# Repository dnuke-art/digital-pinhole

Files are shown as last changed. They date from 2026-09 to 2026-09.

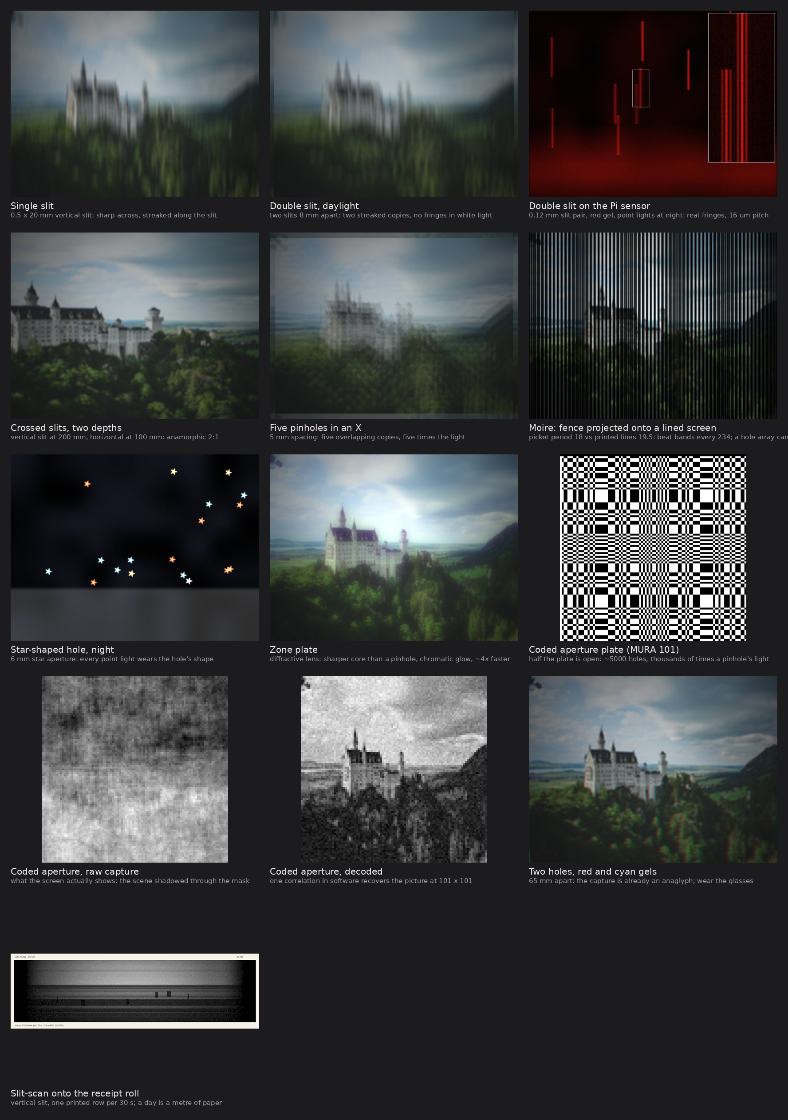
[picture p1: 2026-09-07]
mockups/out/experiments_sheet.png

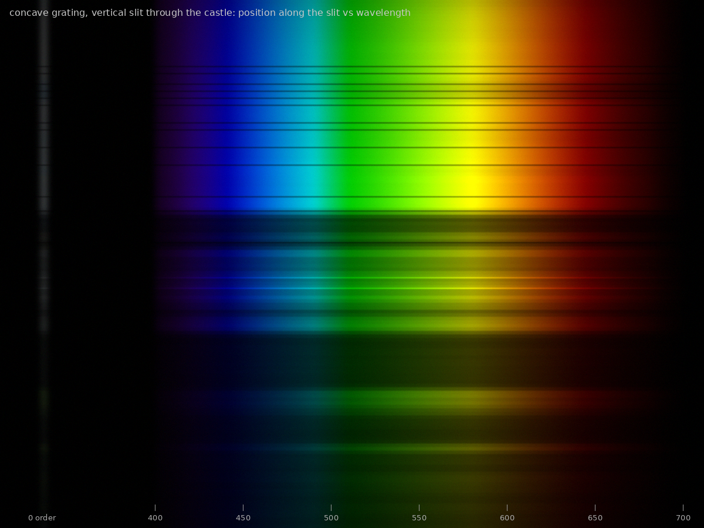
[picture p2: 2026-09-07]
mockups/out/look4_01_spectrograph_day.png

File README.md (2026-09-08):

# Digital Pinhole

Notes toward a digital pinhole camera, started while showing analog pinhole
work at an art show (September 2026). The question was simple: can a pinhole
camera be built with a digital sensing element, and what does it look like?

Short answer: yes, three ways, and the interesting one is a camera obscura
with a small camera inside looking back at the projection.

Loose ideas go in [IDEAS.md](IDEAS.md); the ones that grow get a numbered note below.
Pictures of all of it are in [mockups/](mockups/README.md): simulated output looks, cross-section diagrams, a 3D cutaway. `make` regenerates them.

## Documents

| File | What it covers |
|---|---|
| [docs/01-approaches.md](docs/01-approaches.md) | The three viable designs and how they compare |
| [docs/02-pinhole-physics.md](docs/02-pinhole-physics.md) | Hole sizing, diffraction, resolution vs format, exposure |
| [docs/03-scanner-camera.md](docs/03-scanner-camera.md) | Flatbed scanner as sensor: why it works with a lens and not a pinhole |
| [docs/04-relay-camera-obscura.md](docs/04-relay-camera-obscura.md) | The chosen direction: pinhole box with a relay camera inside |
| [docs/05-thermal-paper.md](docs/05-thermal-paper.md) | Thermal paper: why it cannot be film, sun-trace recorder, receipt printer as output |
| [docs/06-diy-chemistry.md](docs/06-diy-chemistry.md) | DIY chemistry: cyanotype as print side, caffenol, hand-coated emulsion, solargraphy, no-fixer processes |
| [docs/07-wet-plate-pinhole.md](docs/07-wet-plate-pinhole.md) | Wet plate collodion through a pinhole: the wet-window clock, exposure, plate back, chemistry, day-one plan |
| [docs/08-apertures-and-dither.md](docs/08-apertures-and-dither.md) | Slits, shaped holes, zone plate, coded aperture, anaglyph holes, slit-scan, where moire really comes from, dither catalogue |
| [docs/09-diffraction-grating.md](docs/09-diffraction-grating.md) | Grating as lens: linear grating disperses (night spectra), zone plate focuses; numbers, chromatic behaviour, digital deconvolution, how to make one |
| [docs/10-curved-grating.md](docs/10-curved-grating.md) | Curved grating: the Rowland concave-grating spectrograph box, rainbow-ring aperture, FreeCAD Optics Workbench ray traces and what they can and cannot simulate |
| [docs/11-printed-lenses-110-and-instant.md](docs/11-printed-lenses-110-and-instant.md) | The SLO and printed lenses (dip, spin-cure, droplet lens, the relay box as test rig), the 110 cartridge camera, peel-apart and Instax, home-made diffusion transfer, Instax Link as digital output |

## Where this is headed

A wooden or printed box, a pinhole plate on the front, a matte white screen on
the back wall, and a Raspberry Pi camera mounted beside the hole photographing
the screen with multi-minute exposures. It is a slow camera on purpose. The
box is the sculpture and the screen beside it shows what the box has seen.

Next steps once a box size is chosen:

- [x] Mockups: simulated looks, cross-section diagrams, 3D cutaway (mockups/)
- [x] FreeCAD Optics Workbench ray traces of the grating ideas (make optics)
- [ ] Pick box depth and screen size (sets hole diameter and field of view)
- [ ] Decide on a swappable back: screen + camera vs plate holder
- [ ] build123d model of the box, pinhole plate, and camera mount
- [ ] Capture script: long exposure on button press, optional frame stacking
- [ ] Display: e-ink or small monitor next to the prints
- [ ] Receipt printer output: ESC/POS over USB, dither pipeline, auto-cutter
- [ ] Digital negative pipeline: invert, curve, print transparency, cyanotype contact print
- [ ] Wet plate: kit, six 4x5 plates, silver-proof holder, one sunny afternoon
- [ ] Lens plate for the relay box (live mode) and Instax Link output
- [ ] 110 pinhole box and a printed Pa-110 developing reel

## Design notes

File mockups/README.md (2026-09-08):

# Mockups

Plain Python generators (numpy, Pillow, matplotlib, scipy) plus a 3D
section of the relay box (build123d + OpenSCAD). From the repo root:

    make            # everything, about half a minute
    make deps       # check what is installed
    make looks | diagrams | experiments | gratings | render
    make photos     # fetch the sample photos (done automatically when needed)
    make clean      # remove generated images

Or run a generator directly:

    python3 mockups/looks.py       # simulated output images -> out/look_*.png, looks_sheet.png
    python3 mockups/diagrams.py    # cross-section diagrams  -> out/diag_*.png, diagrams_sheet.png
    python3 mockups/render3d.py    # 3D cutaway render        -> out/render_relay_cutaway.png
    python3 mockups/looks2.py      # aperture experiments + dither styles -> out/look2_*.png, dither_*.png, experiments_sheet.png, dither_sheet.png
    python3 mockups/looks3.py      # gratings and zone plate -> out/look3_*.png, grating_sheet.png
    python3 mockups/looks4.py      # curved gratings -> out/look4_*.png, curved_grating_sheet.png
    make optics                    # FreeCAD Optics Workbench ray traces -> out/optics_*.png (needs freecadcmd + addon)

Sample photos in `src/` are from picsum.photos (Unsplash) and are only here
as stand-ins for the simulations.

## Output looks (`out/look_*.png`)

Simulations of what each approach's picture looks like, all from the same
source photo so they compare directly. Sheet: `out/looks_sheet.png`.

| File | Approach | What is simulated |
|---|---|---|
| look_01_relay_digital | relay camera obscura | ~200 points across, cos^4 falloff over a 65° field, flare, long-exposure noise |
| look_02_fullframe_bodycap | full-frame body cap | ~180 points, 90° field falloff |
| look_03_pi_hq_direct | Pi HQ, lens off | ~45 points, steep-ray vignetting and magenta corner shift |
| look_04_receipt | receipt printer | relay frame at 384 dots, Floyd-Steinberg, 58 mm paper with caption |
| look_05_cyanotype | cyanotype from digital negative | Prussian blue on cream paper, brushed coating edge, uneven coat |
| look_06_collodion_landscape | wet plate pinhole, ambrotype | blue/UV-only response (white sky, dark foliage), ~110 points, pour marks, black backing |
| look_07_collodion_portrait | wet plate pinhole, portrait | red lips go black, skin goes luminous |
| look_08_solargraph | solargraphy | months of nested sun arcs, inverted paper-negative tones |
| look_09_sun_trace | sun-trace recorder | thermal strip with a burnt daily arc broken by clouds |
| look_10_heliograph | bitumen heliograph | pewter plate, only highlights harden, very low contrast |

The simulations are optics-first (resolution, falloff, spectral response)
with the surface character (pour marks, paper grain, dither) added on top.
They are for judging the look, not for exposure planning.

## Aperture experiments (`out/look2_*.png`, sheet `experiments_sheet.png`)

Single slit, double slit in daylight, double slit with real fringes on the
Pi sensor, crossed slits (anamorphic), five-hole X, moire from a lined
screen, star-shaped hole at night, zone plate, MURA coded aperture (mask,
raw, decoded), red/cyan two-hole anaglyph, slit-scan receipt strip.
Physics in [docs/08](../docs/08-apertures-and-dither.md).

## Gratings (`out/look3_*.png`, sheet `grating_sheet.png`)

Linear grating over the pinhole at night and in daylight, the zone plate
pattern, the zone plate as captured in white light, and the digital fix
(halo subtraction, luminance from green). Physics in [docs/09](../docs/09-diffraction-grating.md).

## Curved gratings (`out/look4_*.png`, sheet `curved_grating_sheet.png`)

Concave grating spectrograph in daylight (slit through the castle) and at
night (lamp fingerprints), and the circular constant-pitch aperture with
rainbow rings. Physics in [docs/10](../docs/10-curved-grating.md).

## FreeCAD ray traces (`out/optics_*.png`)

`fc_optics.py` runs under FreeCAD's own python (the AppImage in `/opt`,
`freecadcmd` entry point, offscreen Qt) with the OpticsWorkbench addon and writes hit
coordinates to JSON and saves the FreeCAD document (`optics_*.FCStd`, open
it in FreeCAD with the addon installed to see the rays); `optics_plot.py` plots the hits. Two scenes: a 500 l/mm
film behind the pinhole, and the Rowland concave-grating spectrograph.
`make optics` builds both. Not in `make all` because it needs FreeCAD;
`make deps` reports whether the AppImage and the addon are available.
Override with `make optics FREECADCMD="path/to/freecadcmd"`.

## Dither styles (`out/dither_*.png`, sheet `dither_sheet.png`)

The relay frame rendered as Floyd-Steinberg, Atkinson, Bayer 4x4 and 8x8,
45-degree halftone, line screen, Game Boy Camera (128x112, four greens),
CGA palette 1, and 1-bit at 96 px.

## Diagrams (`out/diag_*.png`)

Cross sections in millimetres. Sheet: `out/diagrams_sheet.png`.

1. Relay camera obscura, side section
2. Wet plate pinhole, shallow box with plate holder
3. One body, two backs, exploded
4. Pi HQ camera with the sensor directly behind the hole, 6x scale
5. Full-frame body cap
6. Sun-trace recorder on thermal paper
7. Dubroni-style in-camera wet plate processing
8. Show layout, elevation

## 3D (`out/render_relay_cutaway.png`)

The relay box with the near side wall removed: pinhole plate, camera beside
the hole, Pi, matte screen, light cone, receipt printer on the lid. Built in
build123d so the same file can grow into the real part model.

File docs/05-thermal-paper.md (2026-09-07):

# Thermal paper as film

Asked: can thermal (receipt) paper be used as the film in a pinhole camera?

Not by direct exposure. Two things do work: burning the sun's path with a
lens, and using a thermal printer as the camera's output. The second fits
this project unusually well.

## Why direct exposure cannot work

Thermal paper is a heat medium. The leuco dye and developer in the coating
react when it passes roughly 65 to 70 degrees C (some durable grades need
90+). Light only matters insofar as it heats the sheet.

Rough budget, still air, room temperature:

| Quantity | Value |
|---|---|
| Temperature rise needed | ~45 K |
| Convective loss coefficient | ~10 W/m^2/K |
| Absorptance of white thermal paper | ~0.15 |
| Irradiance needed to hold that rise | 45 * 10 / 0.15 = ~3000 W/m^2, about 3 suns |
| Direct sunlight | ~1000 W/m^2, 1 sun |
| Sunlit scene through an f/300 pinhole | ~0.002 W/m^2 |

A pinhole cannot concentrate light. The most it can ever deliver is slightly
under one sun, and only for an image of the sun itself. A sunlit scene
through the box arrives about six orders of magnitude short. Pre-warming the
sheet toward its threshold does not help: the margin needed is smaller than
the sheet-to-sheet and spot-to-spot variation, so the whole page develops.

Thermal paper also slowly darkens under months of UV and ambient light. Not
usable through a pinhole; too weak and too uneven.

## What works: burning the sun's path

The Campbell-Stokes sunshine recorder is a glass sphere that focuses the sun
onto a card and burns a trace across the day. Concentration through a lens
at f/2 is on the order of thousands of suns, so thermal paper develops
easily and at far lower power than charring. Even a marble or a small cheap
lens will leave a track. Gaps in the trace are clouds.

This is the thermal cousin of solargraphy (months of sun tracks recorded
through a pinhole onto photo paper). It needs a lens because only a lens
concentrates; a big pinhole yields a faint blurred sun disc under one sun
and nothing happens.

As an object: a glass sphere or lens on a stand, a curved thermal paper
strip behind it, changed daily. Thermal paper as film, with the sun as the
only subject.

## The fit for this project: thermal paper as output

Put a receipt printer on the relay box. The camera exposes, prints the frame,
cuts it. Visitors take it. The print fades over the next year or two because
thermal prints do, which suits the medium.

The resolution numbers line up:

| Item | Width | Dots or points across |
|---|---|---|
| Pinhole image on a 250 mm screen | 250 mm | ~200 real points |
| 58 mm receipt printer, 203 dpi | 48 mm printable | 384 |
| 80 mm receipt printer, 203 dpi | 72 mm printable | 576 |

The pinhole image carries fewer real points than the printer has dots. The
receipt loses nothing. Tone comes from dithering (Floyd-Steinberg or ordered
for a coarser look) or from the printer's native grayscale mode where it has
one.

Practical:

- Cheap ESC/POS printers drive from a Pi over USB or serial. `python-escpos`
  handles image printing.
- Pick a printer with an auto-cutter if prints are handed out.
- Thermal paper rolls are cheap; buy phenol-free stock if people will handle
  them.
- Keep the printer out of the light path and its head warmth away from the
  camera.

## Larger thermal prints: laser scanning

For prints bigger than a receipt, scan a low-power laser diode across
fax-roll thermal paper (216 mm width, still sold). Hobby engravers at very
low power develop the coating rather than burn it. Same dither pipeline, one
extra machine. Ventilate: heated thermal coatings release bisphenol vapor.

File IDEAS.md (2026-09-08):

# Ideas

Running list. Loose thoughts land here first; the ones that grow get a
numbered note in `docs/`. Mark status inline.

## Cameras

- **Relay camera obscura** — pinhole box, matte screen, Pi camera beside the
  hole. The main build. → docs/04
- **Walk-in version** — same idea at room scale for the show. Blackout a
  room or a big crate, hole in one wall, camera on a tripod inside doing
  minute-long frames. Morell's move. Untested; needs a dark enough space.
- **Swappable back on the relay box** — screen + Pi camera in one back, a
  4x5/5x7 plate holder in another. Same box shoots digital and wet/dry plate.
- **8x10 or larger relay box** — sharper (~300+ points across) and slower.
  Only if the gallery light budget allows.
- **Full-frame body cap pinhole** — better instrument than the box, worse
  object. Keep as the fast way to make digital pinhole images. → docs/01
- **Pi HQ camera, lens off** — small, bright, soft. Live video outdoors.
  Good for a handheld or a video piece. → docs/01
- **Scanner camera with a lens** — separate project; time-smear aesthetic on
  a letter-size format. Not pinhole. → docs/03
- **Sun-trace recorder** — Campbell-Stokes on thermal paper. Glass sphere or
  lens, curved thermal strip, changed daily. Thermal paper as film for the
  one subject bright enough. → docs/05
- **Solargraphy cans** — months-long pinhole exposures on photo paper, no
  developer. Uses existing cameras. → docs/06

- **Double-slit slide in the Pi HQ cap** — fringes are 16 um on the small
  sensor, invisible on the big screen. Night, red gel, streetlights. → docs/08
- **Zone plate aperture plate** — printed or litho-film, green ~15x sharper
  than the pinhole, ~1.3 stops more focused light plus fog; deconvolve in
  software, luminance from green. → docs/09
- **Grating film slip-over for night** — 500 l/mm, every streetlight writes
  its spectrum 34 mm long. Disperses, does not focus. → docs/09
- **Photon sieve** — zone plate rings as scattered holes; less halo. → docs/09
- **Concave grating spectrograph box** — grating film on a makeup mirror,
  slit and detector strip on the Rowland circle, Pi camera reads the
  spectrum. Streetlight fingerprints at night; spectrum of the day on the
  receipt roll. Ray-traced in FreeCAD: focus 0.14 mm, ~2 mm astigmatism. → docs/10
- **Circular constant-pitch aperture** — diffractive axicon; every night
  light a disc inside a rainbow ring. → docs/10
- **MURA coded aperture plate** — thousands of times the light, decoded in
  software at ~100 points across; the raw capture is its own image. → docs/08
- **Crossed slits at two depths** — anamorphic 2:1 pinhole. → docs/08
- **Star-shaped hole for night lights** — every streetlight wears the
  shape. → docs/08
- **Two gelled holes, 65 mm apart** — capture is already an anaglyph. → docs/08
- **Lined screen for moire** — a hole array cannot make moire (linear);
  a printed grid on the screen can. Swappable screen. → docs/08

- **110 cartridge pinhole camera** — the cartridge is the film gate, the
  transport and the pressure plate, so the camera is a printed box with a
  0.2 mm hole, a thumbwheel and a sliding shutter. Lomography still makes
  the film; a printed Paterson-fit reel develops it at home. Existing
  design: bergytone's 110 pinhole on Thingiverse (0.18 mm hole). Hand-out
  camera for the show; caffenol develops it.
- **Printed lens for the 110 box** — Amos Dudley's SLO (Downloads has the
  STL + .form set, no source) printed its lens on a Form 2 and polished it.
  Dan has printed lenses and smoothed them by resin dip and spray lacquer.
  A single printed element over the 110 gate is the next step up from the
  hole; the tiny format forgives a rough lens.
- **Printed lens plate for the relay box** — swap the pinhole plate for a
  printed singlet at f/4 to f/8: 10 to 12 stops brighter, so the screen goes
  live on the Pi camera. Pinhole mode is slow, lens mode is a live camera
  obscura. The Pi's live view is also the fastest way to judge a printed lens.
- **Droplet lens** — a drop of clear UV resin cured on a printed ring forms a
  spherical cap by surface tension; the print is only the holder and the
  liquid makes the optical surface. No sanding, repeatable by drop volume.
- **Spin-cure the resin dip** — rotate the dipped lens slowly under the UV
  lamp so the coat does not sag into a wedge at the bottom edge.

- **Peel-apart pinhole** — only One Instant (Supersense, Vienna) still makes
  pack film, hand-made, Type 100 size, plus a cheaper DIY kit since late
  2023. ~ISO 100: ~1.6 s at f/200 in sun. Do not print the rollers: build a
  pinhole body that takes a Polaroid 405 back, or put a hole in a Land
  camera lens board. The B&W POS/NEG stock yields a reclaimable negative.
- **Home-made peel-apart (diffusion transfer)** — expose a paper negative,
  sandwich it face to face with a receiver sheet with a developer paste
  between, wait five minutes in the dark, peel. The Photrio "Diffusion
  Transfer Printing recipes" thread is the working lab notebook (receiver
  nucleation layers, thiosulphate/phenol paste). Not instant in the camera,
  but a positive and a negative from one paper exposure, and the same
  rollers-or-squeegee question as pack film. The Supersense DIY kit is the
  packaged version of the same idea.
- **Instax pinhole** — integral film that is cheap and everywhere, ISO 800,
  ~1/9 s at f/150 in sun. Printed bodies exist; Jollylook sells hand-crank
  Instax backs. The hand-out camera with a print in 90 s.

## Outputs

- **Instax Link printer on the relay box** — the Pi prints each frame to
  instant film over Bluetooth (javl/InstaxBLE). Wide Link is 800 x 1260 px,
  far more than the pinhole's ~200 points. A real photograph pops out next
  to the receipt.
- **Peel-apart negative to cyanotype** — One Instant B&W POS/NEG: keep the
  positive, contact print the peeled negative as a cyanotype. All analog,
  all hand-made, two prints per exposure.
- **Peel-apart image transfer** — pull early, press the wet negative onto
  watercolor paper: pigment transfer, the classic pack-film manipulation.

- **Receipt printer on the box** — ESC/POS, dither, auto-cutter, prints
  fade. Resolution match with the pinhole image is near perfect. → docs/05
- **Laser onto fax-roll thermal paper** — bigger thermal prints, hobby
  engraver at very low power. Ventilate. → docs/05
- **Digital negative → cyanotype** — hand-coated, contact printed. The wall
  piece that ties digital capture to hand printing. → docs/06
- **Receipt as oiled paper negative** — print inverted on thermal paper,
  oil it, contact print cyanotype from it. One-afternoon experiment; UV
  opacity of the thermal dye unknown.
- **Slit-scan onto the receipt roll** — one printed row per interval, the
  roll is the film, a day is a metre. Software only. → docs/08
- **Dither switch on the box** — Floyd-Steinberg, Atkinson, Bayer, halftone,
  line screen, Game Boy, CGA. Rotary switch picks the print style. → docs/08
- **Frame stacking vs single long exposure** — different motion character.
  Decide per piece, not globally. → docs/04
- **E-ink display beside the box** — slow refresh matches the medium.
  LCD is easier.

## Process

- **Bitumen heliograph plate in a lens camera obscura** — all-day exposure,
  developed in lavender oil, no fixer, no darkroom. Niépce 1826. → docs/06
- **Calotype paper negatives in the pinhole boxes** — brush-on sensitizing,
  expose damp, develop at once. ~30 min pinhole exposure in sun. → docs/06
- **Identify the Instagram no-fixer glass plate process** — find the
  account. Candidates listed in docs/06.

- **Caffenol** for developing paper in the film boxes. → docs/06
- **Hand-coated liquid emulsion** on glass, wood, found objects, exposed in
  the pinhole boxes. → docs/06
- **Wet plate pinhole** — collodion through a pinhole. Full-sun process,
  ~5 min at f/190, plate must stay wet. Shallow 4x5 box, silver-proof
  holder, damp sponge in the camera. Pursuing. → docs/07
- **Dubroni-style in-camera processing** — sealed plate chamber, fill port,
  drain, red window; no darkbox on location. Prototype after the basic
  process works. → docs/07
- **Pinhole collodion negative → cyanotype** — nineteenth-century end to
  end, all hand-made. → docs/07
- **Stacked frames as dark-frame subtraction** — free noise cleanup on the
  relay camera.

## Dead ends, kept for the record

- Curving the grating film at the pinhole: the hole samples a patch too
  small for curvature to matter.

- A linear grating as the lens: no optical power, it only disperses.

- Pinhole array as a moire generator: convolution is linear, no new
  frequencies. Moire needs multiplication (screen grid, sensor sampling,
  halftone).
- Double slit on the big screen: fringes 0.13 mm, a tenth of a screen
  point, washed out in white light.

- Pinhole directly onto thermal paper: needs ~3 suns, pinhole delivers <1.
- Cyanotype in a pinhole camera: ~8 years at f/300.
- Flatbed scanner behind a pinhole: ~3000x short on light.
- Pi camera with lens on behind a hole: that is a lens at f/60, not a
  pinhole.

## Questions to settle before building

- Box depth and screen size.
- Front-projection matte card vs rear-projection second chamber.
- Which Pi camera (Module 3 Wide vs HQ) — set by box depth.
- What the box points at during the show.
- Plate holder standard for the swappable back (4x5 is cheapest and most
  available; 5x7 is closer to the screen size).

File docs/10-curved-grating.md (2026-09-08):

# Curving the grating

Asked: what if the diffraction grating is curved? And can this be simulated
in FreeCAD's Optics Workbench?

Curving is the one move that turns a grating into a real imaging element,
and it is how the first lensless spectrographs worked. It only matters when
the grating is large. Mockups: `mockups/out/look4_*.png` (sheet
`curved_grating_sheet.png`), diagram `diag_09_rowland.png`, and two ray
traces from FreeCAD, `optics_grating.png` and `optics_rowland.png`.

## Three different things "curved grating" can mean

1. **Bending the film at the pinhole.** Does nothing. The hole samples a
   patch a fraction of a millimetre across; curvature over that patch is
   invisible. A film wrapped around the hole as a cylinder makes every ray
   hit at normal incidence, which slightly straightens the off-axis
   "smile" of the spectra, and that is all.
2. **Curving the lines.** Constant-pitch concentric rings are a diffractive
   axicon: every wavelength is thrown outward by the same angle, so a point
   light becomes a disc inside a rainbow ring. Rings whose pitch shrinks
   outward are the zone plate (see [09-diffraction-grating.md](09-diffraction-grating.md)).
3. **Curving the surface, big, and using it as the mirror.** A reflection
   grating ruled on a concave spherical mirror focuses and disperses at
   once: Rowland's concave grating, 1882. The mirror is the lens, the
   rulings are the prism, no other optic anywhere. This is the real answer.

## The concave grating spectrograph

Geometry: mirror radius R, grating at its vertex. Draw a circle of diameter
R tangent to the grating (the Rowland circle). A slit anywhere on that
circle is imaged, dispersed, back onto the circle. Each wavelength lands at
its own point; the detector is an arc of the circle.

For the box: R = 400 mm (f = 200), 500 lines/mm, slit 20 degrees off the
normal on the circle. Positions along the arc from the centre of curvature:

| Wavelength | Diffraction angle | Arc position |
|---|---|---|
| 700 nm | -0.5° | 3 mm |
| 550 nm | 3.8° | 27 mm |
| 400 nm | 8.2° | 57 mm |

Sixty millimetres of spectrum. Spectral resolution is set by the slit:
about 0.1 mm per nanometre at this dispersion, so a 0.5 mm slit resolves
roughly 5 nm, enough to tell a sodium lamp from an LED from neon at a
glance. Each point along the slit's height writes its own horizontal
spectrum, so the picture is position-along-the-slit versus wavelength.

What it makes:

- **Daylight.** Aim the slit through the scene; the image is the scene's
  colour, spread out. Sky is a broad blue ramp, a sunlit wall is a
  continuum, foliage dips in the red.
- **Night.** Every streetlight writes its fingerprint: sodium a yellow
  pair of lines, white LED a blue spike plus a yellow hump, neon a comb of
  red lines, mercury three sharp lines, incandescent a smooth ramp rising to
  red, a laser pointer one line. Mockup: `look4_02_spectrograph_night`.
- **Over time.** Combine with the slit-scan idea: one printed row per
  interval, and the receipt roll becomes the spectrum of the day. In 1-bit
  it prints as a barcode that changes with the weather.

DIY concave grating: a flexible 500 l/mm film grating laminated onto a
concave makeup mirror. The light passes the film twice (in and out) with
the mirror between, so it disperses roughly twice as hard as a single pass
and loses some efficiency, but it works; DIY spectroscope builders do it.
A 2x to 3x makeup mirror has a focal length around 125 to 250 mm. Proper
concave holographic gratings are a few hundred dollars from Edmund or
Thorlabs.

## Ray-traced in FreeCAD

FreeCAD's Optics Workbench addon (chbergmann/OpticsWorkbench) is a
geometric ray tracer: reflection, refraction, absorbers, and diffraction
gratings via the grating equation. It runs headless under FreeCAD's own
python once two GUI hooks are stubbed: the AppImage in `/opt` run through
its `freecadcmd` entry point with `QT_QPA_PLATFORM=offscreen` (without the
offscreen setting it waits for a display; with `--console` instead of
`freecadcmd` it finishes the script and then sits in an interactive prompt). The script is `mockups/fc_optics.py`,
the plotter `mockups/optics_plot.py`, target `make optics`. The addon lives
in `~/.local/share/FreeCAD/Mod/OpticsWorkbench`. The script also saves the
FreeCAD documents (`mockups/out/optics_*.FCStd`), which open in the GUI with
the addon installed and show the rays, grating and detector.

**Linear grating behind the pinhole** (`optics_grating.png`): 315 rays,
15 scene directions, 7 wavelengths, orders -1, 0, +1, onto the 250 x 200 mm
screen. The traced first-order positions match `200 tan(asin(lambda / d))`
to 0.5 percent (the film sits 1 mm behind the hole, which accounts for the
difference). Off-axis rows show the spectra curving into a "smile", which
is conical diffraction and is real.

**Rowland spectrograph** (`optics_rowland.png`): 330 rays from three
heights on the slit, fanned across 24 mm of grating width and 16 mm of
height. Results:

| Wavelength | Traced arc position | Spread across the fan | Vertical spread (slit point at z = 0) |
|---|---|---|---|
| 400 nm | 57.2 mm | 0.14 mm | ±1.2 mm |
| 550 nm | 26.9 mm | 0.13 mm | ±1.1 mm |
| 700 nm | 3.3 mm | 0.15 mm | ±1.0 mm |

So the tangential focus on the Rowland circle is essentially perfect (a
tenth of a millimetre from a 24 mm fan), the positions match the grating
equation, and the vertical direction is not focused: a point on the slit
smears to about 2 mm tall. That is the classic astigmatism of the concave
grating, and it is harmless here because the slit is a line anyway. A slit
point 4 mm up images 4 mm down, inverted 1:1. The zero-order (specular)
rays land at the mirror-image angle, 140 mm along the arc the other way,
and the +1 order goes further still, past the specular.

One convention to know: the addon's order sign is such that -1 diffracts
back toward the grating normal from a slit at +20 degrees. Trace both and
use the one that lands where you want.

## What the workbench can and cannot simulate

| Idea | Optics Workbench | Notes |
|---|---|---|
| Pinhole geometry, field of view, vignetting | yes | geometric; no diffraction blur |
| Relay camera field, anaglyph holes, crossed slits | yes | geometric |
| Linear grating over the hole, spectra positions | yes | grating equation, any order |
| Concave grating spectrograph, Rowland focus, astigmatism | yes | shown above |
| Fresnel lens / any refractive optic in the box | yes | Snell's law, Sellmeier materials |
| Zone plate | no | needs radially varying pitch and diffraction efficiency |
| Double-slit fringes, coded aperture, moire | no | wave optics or image processing, not ray tracing |
| Pinhole sharpness vs hole size | no | diffraction; use the formulas in [02](02-pinhole-physics.md) |

Where it earns its place: laying out the Rowland box (slit, grating and
detector all on one circle inside a wedge-shaped box), checking that the
Pi camera's field covers the spectrum strip, and sizing the film grating
on the makeup mirror. For everything wave-shaped the numpy mockups are the
right tool.

## Build idea

Diagram: `diag_09_rowland.png`. A shallow wedge box. Makeup mirror with
grating film at the narrow end. Slit and a curved white strip on the
Rowland circle at the wide end, the strip covering about 60 mm of arc.
Pi camera on the wide end looking at the strip. Same Pi, same printer,
same software as the relay box: this is the second head for it.

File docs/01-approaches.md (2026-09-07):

# Three ways to build a digital pinhole camera

All three work. They differ in how much you build and in how large the
"format" is, which is what sets pinhole image quality (see
[02-pinhole-physics.md](02-pinhole-physics.md)).

## 1. Body cap on a mirrorless camera

Drill or laser-cut a hole in a body cap, mount it, shoot. Zero build effort and
the sensor is large, which is the single biggest factor in pinhole sharpness.

- Sony E flange distance is 18 mm, giving an optimum hole of about 0.10 mm and
  f/180.
- Sensor dust is brutally visible at these apertures. Clean the sensor first.
- Exposure is friendly: about 1/6 s in sunlight at ISO 800, seconds to minutes
  indoors.
- The sensor stack (cover glass, IR filter, microlenses) expects near-normal
  incidence. With the hole only 18 mm from the sensor the corners get steep
  rays, so expect some vignetting and color shift at the edges.

Good for making pinhole images quickly. Not much of an object to show.

## 2. Raspberry Pi HQ camera in a box you make

The HQ camera (Sony IMX477, 1/2.3", 6.17 x 4.55 mm) has a C/CS mount. Remove
the lens and a printed cap with a pinhole disc bolts straight on.

- Exposures up to several minutes under libcamera.
- Live view on a screen, which film pinhole can never do. Good gallery
  behavior: the box is the object, the screen shows what it sees.
- The sensor is tiny, so the image is very soft. A hole 5 mm from the sensor
  wants a 0.07 mm hole at f/70 and resolves roughly 45 points across the
  frame. Dreamy, not sharp.
- Same steep-ray vignetting issue as above, worse because the hole is closer.
  Moving the hole back trades field of view for evenness.

Good if the soft look is the point. Sharpness will never approach 4x5 film.

## 3. Camera obscura with a relay camera inside

A large pinhole box projects onto a matte screen on the back wall. A small
camera mounted beside the hole on the inside of the front wall photographs the
screen with a long exposure.

- The pinhole geometry is large format, so softness, vignetting and
  perspective all come from the pinhole, not from the little camera.
- The relay camera absorbs the light deficit because it has a real shutter
  and ISO.
- Costs about four stops of light versus a sensor at the screen plane, so it
  is a slow camera. Suits the medium.
- Cheapest large-format digital pinhole there is.

This is the direction the project is taking. Details in
[04-relay-camera-obscura.md](04-relay-camera-obscura.md).

## Comparison

| Setup | Hole-to-image distance | Hole | f-number | Resolvable points across frame |
|---|---|---|---|---|
| Full-frame body cap (Sony E) | 18 mm | 0.10 mm | f/180 | ~180 |
| Pi HQ camera, hole close to sensor | 5 mm | 0.07 mm | f/70 | ~45 |
| 4x5-style box, sensor at screen plane | 150 mm | 0.29 mm | f/520 | ~200 |
| 200 mm deep box with relay camera | 200 mm | 0.63 mm | f/317 | ~200 |

## Rejected: flatbed scanner as the sensor

Scanner cameras are real and lovely but they need roughly f/5.6 worth of light
and a pinhole delivers about three thousand times less. Full reasoning in
[03-scanner-camera.md](03-scanner-camera.md).

## Sensor directly behind the hole vs a screen

Asked after the relay design was sketched: why not put a wide Pi camera right
behind the pinhole?

Two different things hide in that question.

**Lens removed, bare sensor behind the hole.** This is approach 2. Its one big
advantage is light: at 5 mm the pinhole runs about f/70 with no screen loss,
roughly eight stops brighter than the relay box. Live video outdoors, seconds
indoors. It gives up format: the pinhole image forms on a 4.6 mm sensor
instead of a 250 mm screen, so ~45 points across instead of ~200, plus
steep-ray vignetting and color shift in the corners. Practical snag: the
Module 3 lens lives in an autofocus module and is not meant to come off. The
v2 module lens unscrews; the HQ and Global Shutter cameras are built for lens
swaps.

**Lens kept on, hole in front of it.** Not a pinhole camera. The lens forms
the image and the hole is an aperture stop; a 0.6 mm hole on a Module 3 Wide
is about f/4.6 and makes a sharp deep-focus lens photo. Shrink the hole until
diffraction dominates and it is a lens shot at f/60. A hole a few millimeters
ahead of the lens also crops the field into a circle. Can look pinhole-ish
but the rendering is the lens's.

The screen buys exactly one thing, format size, and the relay camera absorbs
the four-stop cost because it has a shutter and ISO.

| Design | Format width | Points across | Effective speed | Live view? |
|---|---|---|---|---|
| Pi camera, lens off, behind hole | 4.6 mm | ~45 | f/70 | yes, outdoors |
| Full-frame body cap | 36 mm | ~180 | f/180 | slow, seconds |
| Relay box, 250 mm screen | 250 mm | ~200 | f/317 + 4 stops | no |

Worth keeping in view: a used full-frame body with a body cap pinhole matches
the relay box's sharpness at about five stops brighter, tethers over USB, and
costs a few hundred dollars used. As an instrument it is better. The box wins
on being a made object at the scale of the film cameras, and on scaling to
8x10 and beyond where no sensor follows.

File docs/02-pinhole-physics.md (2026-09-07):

# Pinhole physics, as much as the project needs

## Optimum hole diameter

Two blurs compete. A bigger hole projects a bigger geometric spot; a smaller
hole diffracts more. The crossover (Lord Rayleigh's form, widely used) is

    d = 1.9 * sqrt(f * lambda)

where `f` is hole-to-image distance and `lambda` is the wavelength, taken as
550 nm (green, mid-visible). The f-number is then `N = f / d`.

| f (hole to image) | d | N |
|---|---|---|
| 5 mm | 0.07 mm | f/70 |
| 18 mm | 0.10 mm | f/180 |
| 50 mm | 0.31 mm | f/160 |
| 100 mm | 0.45 mm | f/220 |
| 150 mm | 0.55 mm | f/270 |
| 200 mm | 0.63 mm | f/317 |
| 300 mm | 0.77 mm | f/390 |

Note the f-number keeps rising with depth. Bigger boxes are slower.

## Resolution scales with format, not pixels

At the optimum, the blur spot on the image plane is roughly twice the hole
diameter. So the number of resolvable points across the frame is about

    frame_width / (2 * d)

Since `d` grows only with the square root of `f`, and frame width grows
linearly with `f` for a given field of view, larger formats are sharper.
This is why 4x5 and 8x10 pinhole prints look the way they do and why a
phone-sensor-sized pinhole camera never will.

A 12 MP sensor behind a correctly sized pinhole is capturing a picture that
holds maybe 50 to 200 real points across. Any sensor with more pixels than
that is oversampling, which is fine, but it buys nothing.

Consequence for the design: the sensing element's pixel count does not
matter. The size of the image plane does.

## Exposure

Sunny 16 rule: at ISO 100 in full sun, 1/100 s at f/16. Scale by
`(N / 16)^2` for the pinhole's f-number.

| Pinhole N | Factor vs f/16 | Sunlight, ISO 100 | Sunlight, ISO 800 |
|---|---|---|---|
| f/70 | 19 | 0.2 s | 1/40 s |
| f/180 | 127 | 1.3 s | 1/6 s |
| f/300 | 352 | 3.5 s | 0.44 s |
| f/500 | 977 | 10 s | 1.2 s |

Scenes darker than sunlight add stops on top of that:

| Scene | Stops below full sun | Multiply exposure by |
|---|---|---|
| Overcast | 3 | 8 |
| Open shade | 3-4 | 8-16 |
| Bright interior | 8 | 256 |
| Dim interior | 10 | 1024 |

Reciprocity failure is a film problem. Digital sensors do not suffer it, but
long exposures accumulate dark-current noise and hot pixels. Dark-frame
subtraction or stacking many shorter frames handles that.

## Small-sensor caveat: steep rays

Consumer sensors have microlenses over each pixel that assume light arriving
close to perpendicular, and a cover glass / IR filter stack that shifts color
with angle. A pinhole close to a sensor sends corner rays in at steep angles,
giving vignetting and a color cast at the edges. Moving the hole further
back reduces the effect and narrows the field of view. Large-format
projection onto a screen avoids the issue entirely, which is one more point
for the relay design.

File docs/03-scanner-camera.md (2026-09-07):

# Flatbed scanner as the sensing element

The "scanner camera" is a real thing from the mid-2000s: Michael Golembewski's
Scanner Photography Project and Andrew Davidhazy's strip-photography work at
RIT are the most visible examples. This note records why it is not a pinhole
camera and probably cannot be made into one.

## How scanner cameras work

A flatbed scanner is a line sensor swept across the glass by a carriage.

1. Remove the lid.
2. Disable or mask the lamp.
3. Mount the scanner at the back of a big box with a lens on the front.
4. The projected image lands on the glass plane, where the scanner's own
   optics are focused.
5. Scan. Each column is captured at a different moment, which produces the
   signature time-smear on anything that moves.

The result is a letter-size "sensor" for the price of an old scanner. The
time-smear is a feature: it is slit-scan photography with a huge format.

## Why it needs a lens and not a pinhole

A scanner is built to read paper lit by a lamp a few millimeters away. Its
per-line exposure is set by the carriage speed, roughly a millisecond, and
there is no shutter to hold open. In practice a scanner camera in daylight
wants about the same light as an ordinary camera at f/5.6.

| Aperture | Light at sensor, relative | On a flatbed |
|---|---|---|
| f/5.6 lens, daylight | 1 | works; what the scanner-camera builders used |
| f/32 lens stopped down | 1/33 | marginal; slowest scan setting plus software gain |
| f/300 pinhole, letter-size box | 1/3000 | not close |

Scanning at the highest resolution slows the carriage and lengthens line
integration, worth maybe a factor of ten. That does not cover a factor of
three thousand. Some SANE backends expose the CCD exposure time and a few
people have hacked it, but the scanner's own optics accept light only in a
narrow cone, so the corners go dark anyway.

Better Light and the other professional 4x5 scanning backs of the era were
this idea done properly. Even they wanted f/8, hot studio light and scans of
a minute or more. That is the ceiling for line-sensor capture.

## Hardware constraints if you try anyway

- **CCD, not CIS.** Thin modern scanners (the Canon LiDE family and most
  cheap units) use a contact image sensor with a rod-lens array that only
  sees about a millimeter above the glass. They cannot image a projected
  picture at all. Older, thicker Epson and HP units with a reduction lens
  inside the body can.
- **Firmware fights you.** Scanners calibrate against a white strip with the
  lamp on before every pass and may refuse to scan without it. Getting a raw,
  lamp-off pass means the SANE backend and flag fiddling.
- **Focus plane is the glass.** The scanner's optics have a few millimeters
  of depth of focus. The projected image has to land on the glass plane.

## Verdict

A scanner camera with a proper lens is a good separate project if the
time-smear aesthetic appeals. As a pinhole camera it is a photon-starvation
problem with no fix. The large-format digital pinhole look comes from the
relay camera obscura instead: [04-relay-camera-obscura.md](04-relay-camera-obscura.md).

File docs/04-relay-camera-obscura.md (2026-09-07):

# Relay camera obscura

The chosen design. A pinhole box projects onto a matte screen on its back
wall, and a small camera mounted beside the hole on the inside of the front
wall photographs the screen with a long exposure.

This is what Abelardo Morell does at room scale: black out a window, cut a
hole, photograph the picture that lands on the far wall with a long
exposure. Ours is the same thing in a box.

```
   front wall                                    back wall
   +-----------------------------------------------+
   |  o  <- pinhole                                |
   |                                               |
   | [cam] -------- looks at screen -------->  ####|  matte white screen
   |                                           ####|
   |  black interior                           ####|
   +-----------------------------------------------+
   <------------------ depth f -------------------->
```

## Geometry

- **The camera never shadows the image.** The pinhole cone diverges from the
  hole toward the back wall. Anything on the front wall beside the hole is
  outside the cone.
- **Off-axis is fine.** Mount the camera a couple of centimeters from the hole.
  Keystone is negligible at that offset, or correct it once with a homography.
- **The screen is the back wall.** Matte white card. Nothing glossy.
- **Everything else is black.** Flocking or flat black paint on all interior
  surfaces, especially the front wall around the camera. Otherwise the screen
  lights the interior and the interior fogs the screen.
- **Relay camera field of view.** To see a 250 mm screen from 200 mm away
  the camera needs about a 65 degree horizontal field. Pi Camera Module 3
  Wide covers it; a standard Module 3 or HQ camera with a short lens also
  works with a deeper box.
- **Resolution is not a concern.** A 200 mm deep box wants a 0.63 mm hole,
  giving a blur spot near 1.2 mm on the screen. The pinhole image holds
  about 200 resolvable points across. Any 1080p sensor captures all of it.

## Light budget

A matte screen scatters the pinhole image in all directions and the relay
camera collects only a small cone of it. Relative to a sensor sitting at the
screen plane, the relay loses about

    albedo / (4 * N_relay^2)

which at f/2 and a 0.9 albedo screen is roughly 1/18, or four stops.

| Scene | Sensor at screen, f/300, ISO 100 | Relay at f/2, ISO 800 |
|---|---|---|
| Sunlit exterior | 3.5 s | 8 s |
| Overcast or open shade | 30 s | 1 min |
| Bright interior room | 15 min | 30 min |

So it is a slow camera. Pointed out a window or set outside it makes a frame
every few seconds to a minute. Inside a gallery it needs the same patience as
a film box, or the equivalent trick of stacking many shorter frames, which
also cleans up sensor noise.

Ways to buy back light, in order of preference:

1. Higher relay ISO (noise is fixable by stacking).
2. Faster relay lens (f/1.4 board lenses exist, but corners suffer).
3. Larger pinhole. Softer, and the box gets a stop per doubling of area.
4. Shallower box. Lower f-number but wider angle and more screen falloff.

## Relay camera choice

The exposure ceiling decides it.

| Camera | Max single exposure | Notes |
|---|---|---|
| USB webcam | ~1 s | Noisy; can only work by stacking frames |
| Pi Camera Module 3 / 3 Wide | ~112 s (libcamera) | Wide variant fits shallow boxes; autofocus |
| Pi HQ camera (IMX477) | ~670 s (libcamera) | Larger sensor, cleaner; needs a CS lens |
| Mirrorless body | bulb | Best quality, biggest box, no live feed |

The Pi cameras produce a genuine long exposure with the same motion-blur
character as film. Stacking gives the same total light but averages motion
differently, which is a different look. Pick one deliberately.

Practical details:

- Kill every LED on the camera and Pi. Tape over what cannot be disabled.
- Remove the IR filter from nothing. Keep it; the screen is neutral.
- Lock white balance and gain per session. Auto anything drifts across
  minute-long frames.
- Shoot raw or at least uncompressed to keep the shadow tones the screen
  gives you.

## Build sketch

- Box: plywood or printed, roughly 250 x 200 mm screen, 200 mm deep. Light
  tight seams; a lip on the lid.
- Pinhole plate: 0.05 mm brass shim or a laser-drilled disc in a printed
  holder, 0.6 mm hole for 200 mm depth. Make the plate swappable so
  different holes can be tried.
- Camera mount: printed bracket on the inside of the front wall, 20 to
  30 mm from the hole, aimed at screen center.
- Electronics: Pi Zero 2 W, Camera Module 3 Wide, one button, optional
  small display or e-ink panel on the outside.
- Software: one script. Button press starts an exposure of a configured
  length (or a stack of N frames), writes a file, pushes it to the display
  and to a folder the gallery screen watches.

## Show behavior

The box sits with the prints. It faces a window or a lit tableau. Every few
minutes it takes a frame and the screen beside it updates. Visitors see a
pinhole image forming with the same slowness the film prints were made with,
but on a screen, which makes the link between the two bodies of work
legible without explanation.

## Open questions

- Box size. Larger is sharper and slower. 8x10 inch screen at 300 mm depth
  is a real option if the gallery light allows it.
- Screen material. Plain matte card vs a slight-gain rear projection screen
  with the camera behind it (a second chamber). Front projection is simpler
  and is the plan unless the four-stop loss proves too much.
- Display. Live e-ink is slow and matches the medium; an LCD is easier.

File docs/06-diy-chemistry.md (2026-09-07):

# Low-fi chemical processes you can do yourself

Asked: what DIY chemical process could the digital pinhole work feed, or
replace the digital capture? Cyanotype specifically.

The one fact that sorts every process is speed. Everything you can sensitize
in a kitchen is a contact-printing process. Only silver emulsions are fast
enough to expose inside a camera.

## Cyanotype in the camera: no

A cyanotype contact print in full sun takes about ten minutes. Inside a
camera the paper sees the scene through the aperture, which cuts the light
by about `4 * N^2 / albedo` relative to contact printing (albedo of a sunlit
white surface ~0.8).

| Where the paper sits | Light vs contact | Ten-minute contact print becomes |
|---|---|---|
| Contact frame in sun | 1 | 10 min |
| Behind an f/1 Fresnel camera obscura | 1/5 | ~1 hour |
| Behind an f/2.8 lens | 1/40 | ~7 hours full sun |
| Behind the f/300 pinhole box | 1/450,000 | ~8 years |

In-camera cyanotypes exist, made with big fast lenses over a day, and they
mostly record sky because UV drives the reaction. Through a pinhole it is
not a thing. Salt prints, anthotypes, lumen prints and chlorophyll prints are
slower still.

## Cyanotype as the print side: yes

This is the fit. The relay camera captures; the file is inverted and printed
on inkjet transparency; the transparency is contact printed by hand in sun or
under a UV lamp. It closes the loop between digital capture and hand
printing, and hangs beside the film pinholes as one body of work.

- The pinhole image carries ~200 real points across. A rough transparency
  loses nothing.
- Chemistry: ferric ammonium citrate + potassium ferricyanide, mixed 1:1
  before coating. Safest of the historical processes. Develop by rinsing in
  water. About $20 covers a show's worth of prints.
- Coat with a foam brush on watercolor paper, dry in the dark, expose 5 to
  20 minutes in sun (or a UV nail lamp / face-tanner tube box), rinse until
  the water runs clear, dry. Blue deepens over 24 hours.
- Tone in strong tea or coffee for brown-black; bleach lightly in washing
  soda first for split tones.
- Digital negative: invert, then apply a curve so the print's tonal range
  matches (cyanotype needs a dense, contrasty negative). Print on Pictorico
  or any inkjet transparency; a laser-printer overhead transparency works at
  the low end.

Experiment worth an afternoon: print the negative on the receipt printer
(see [05-thermal-paper.md](05-thermal-paper.md)), oil the receipt to make it
translucent, and contact print from that. Oiled paper negatives are a
classic technique. Open question is whether the thermal dye blocks enough
UV to print with contrast.

## In-camera chemistry you can do yourself

Silver paper, the same as in the film boxes, with two ways to make it more
homebrew, plus one no-development route.

- **Caffenol developer.** Instant coffee, washing soda (sodium carbonate)
  and vitamin C (ascorbic acid). Develops paper and film. Stop in water or
  dilute vinegar. Fix in sodium thiosulfate, sold as pool and aquarium
  dechlorinator. Nothing that can't come from a grocery and a pool store.
- **Hand-coated emulsion.** Liquid silver emulsion (Foma, Liquid Light)
  brushed onto paper, glass, wood, ceramic. Roughly ISO 1 to 3. Minutes in
  sun through a pinhole. Develop and fix as paper. Making the emulsion from
  scratch (silver nitrate + potassium bromide in gelatin) is a deeper rabbit
  hole, documented at The Light Farm.
- **Solargraphy.** Photo paper in a pinhole can, weeks to months of
  exposure, no developer. The latent image prints out visibly. Scan it (once;
  scanning light degrades it) and invert. Uses the cameras already built.

## Rough speed ladder

| Process | Approx. ISO | Pinhole exposure in sun at ~f/200 | Where it works |
|---|---|---|---|
| Silver gelatin paper | 3 to 6 | tens of seconds to minutes | in camera |
| Liquid emulsion / dry plate | 1 to 3 | minutes | in camera |
| Wet collodion | ~0.5 | minutes, must stay wet | in camera, not low-fi |
| Cyanotype | ~1e-6 | years | contact only |
| Salt print | lower than cyanotype | no | contact only |
| Anthotype | days in a contact frame | no | contact only |

ISO figures for the contact processes are back-of-envelope from contact
times and mean nothing beyond ordering.

## Where this leaves the project

Two chemical outputs sit naturally on the relay box:

1. A receipt printer for the instant, fading take-away.
2. A digital negative and hand-coated cyanotype for the wall.

And the film boxes keep doing what they do, now with caffenol if the point
is to own every step.

## Wet plate collodion (the Instagram "flow it on a glass plate" process)

Bare glass to finished image in about fifteen minutes, every step wet. The
tacky set after pouring looks like drying but is not; once collodion truly
dries it loses almost all sensitivity, so the window is ~10 to 15 minutes.

1. Pour salted collodion onto the plate, tilt to flow to the corners, drain
   the excess off one corner. Sets to a gel in about a minute.
2. Silver nitrate bath, 3 to 5 minutes, in the dark. This sensitizes it.
3. Load wet, expose, develop within minutes (iron sulfate developer). Fix in
   plain hypo. Rinse, dry, varnish (sandarac / lavender oil).

Glass with black backing = ambrotype. Blackened aluminum = tintype. Both are
direct positives, one of a kind. Most people online shoot tintypes on
"trophy aluminum" because it is cheap and does not break.

Speed ~ISO 0.5 to 1, blue and UV sensitive only: skies white, reds black.

| Setup | Exposure in full sun |
|---|---|
| Lens camera at f/4 | ~1 s |
| Pinhole at f/200 | ~5 min |
| Pinhole at f/300, open shade | ~30 min, plate dries out first |

Wet plate pinhole in sun works. Shade and overcast run out the clock.

Hazards, complete list: collodion is ether + alcohol (no flames, ventilate);
silver nitrate stains skin black for a week and is caustic to eyes (gloves,
glasses); choose a cadmium-free collodion formula; fix in sodium thiosulfate
rather than the traditional potassium cyanide. Kits: Bostick & Sullivan and
similar.

**Dry-plate cousin without the timer:** liquid silver emulsion flowed onto
glass the same way, dried in the dark, stored for weeks. ISO 1 to 3, develops
in paper developer, gives a negative not a direct positive. Same look on
glass, no wet window.

**Design implication for the relay box:** make the back swappable. One back
holds the matte screen and the Pi camera; another is a 4x5 or 5x7 plate
holder. Same pinhole, same box, digital frames for the screen and plates for
the wall.

## Old processes with no fixer

Recalled from an Instagram video: a very old process, glass plate, flowed or
wiped on, dried, exposed and developed immediately, possibly no fixer. If the
no-fixer memory is right it is not collodion (which needs a fix, and the fix
is the dramatic clearing moment). Candidates, oldest first:

- **Bitumen heliograph, Niépce 1826.** Bitumen of Judea in lavender oil,
  flowed on pewter or glass, dried. Light hardens it. Develop by washing in
  lavender oil + petroleum, dissolving the unexposed parts. No fixer because
  nothing is left to fix. The oldest photograph. Hours to days of full sun
  with a lens.
- **Physautotype, Niépce & Daguerre 1832.** Lavender oil residue in alcohol
  flowed on a silver plate, dries white. Expose, develop over petroleum
  vapor. Direct positive, no fixer. Hours.
- **Dichromated gelatin / gum, 1850s (Talbot, Poitevin).** Gelatin +
  potassium dichromate flowed on glass, dried. Light hardens it. Develop in
  warm water. No fixer. Minutes in a contact frame. Hexavalent chromium:
  handle accordingly.
- **Cyanotype on glass, Herschel 1842.** Gelatin-subbed glass, water wash.
  No fixer. Contact only.
- **Calotype, Talbot 1841** (if "glass" is the fuzzy part). Silver nitrate
  brushed onto iodized paper, exposed damp, developed immediately in gallic
  acid. Originally stabilized with salt/bromide rather than fixed. Works in
  a camera: ~1 min at f/15 in sun, so roughly half an hour through a
  pinhole. The closest "wipe on, expose, develop now" process a pinhole box
  can actually use.

### Why no-fixer means slow

In every fixer-free process, light does the whole job directly by changing
the solubility of the coating. In silver processes light makes only a faint
latent image and the developer amplifies it by roughly 10^9. Fixer exists to
clear the unexposed silver the developer left behind. No fixer means no
amplification, which means on the order of 10^4 to 10^6 times more light.
Every no-fixer process is therefore contact-print speed or
hours-with-a-fast-lens speed, never pinhole speed.

| Process | Fixer | Speed in camera | Pinhole viable |
|---|---|---|---|
| Wet collodion | yes | ~5 min at f/200 in sun | yes |
| Calotype paper negative | salt stabilizer, later hypo | ~1 min at f/15 in sun | marginal, ~30 min |
| Dichromated gelatin | none | contact only | no |
| Bitumen heliograph | none | hours with a lens | no |
| Cyanotype | none | contact only | no |

Open: find the account and identify the actual process.

Piece idea: bitumen heliograph in a lens camera obscura. A plate that takes
all day to expose, developed in lavender oil, no darkroom at all.

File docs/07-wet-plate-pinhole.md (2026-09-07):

# Wet plate pinhole

Collodion is the one hand-coated process fast enough to expose through a
pinhole. The combination has a hard constraint the digital box does not: the
plate must be poured, sensitized, exposed, and developed before it dries,
roughly ten to fifteen minutes end to end. Everything below follows from
that clock.

## The clock

| Step | Time | Notes |
|---|---|---|
| Pour and set | ~1 min | Tacky gel, looks dry, is not |
| Silver bath | 3 to 5 min | In the dark or under red light |
| Load, walk to camera, uncap | 1 to 2 min | Holder must be light tight and silver proof |
| Exposure | budget | Whatever is left |
| Develop | 15 to 30 s | Iron sulfate, pour on, rock, stop with water |
| Fix, rinse | 2 to 5 min | Hypo; can be in daylight |

On a warm dry day the exposure budget is about five to eight minutes. On a
cool humid day it stretches to fifteen. Once the collodion dries it stops
being sensitive, and a plate that dries mid-exposure develops with a hard
edge where the wet front stopped.

## Exposure through a pinhole

Collodion is about ISO 0.5 to 1 in visible light and only responds to blue
and UV. Two things help the pinhole case:

- **Pinholes pass UV.** Glass lenses absorb much of it. Collodion through a
  pinhole is somewhat faster relative to a lens camera than the visible-ISO
  arithmetic suggests. Treat the numbers below as pessimistic.
- **Shallow boxes are fast.** The f-number falls with depth (see
  [02-pinhole-physics.md](02-pinhole-physics.md)). A plate camera wants a
  shallower box than the digital one.

| Plate | Depth | Optimum hole | f-number | Full sun, ISO 0.5 | Open shade |
|---|---|---|---|---|---|
| 4x5 | 75 mm | 0.39 mm | f/190 | ~5 min | ~40 min, plate dries |
| 4x5 | 100 mm | 0.45 mm | f/220 | ~6 min | no |
| 5x7 | 150 mm | 0.55 mm | f/270 | ~10 min | no |
| 5x7, hole opened to 0.8 mm | 150 mm | 0.80 mm | f/190 | ~5 min | no |

Wet plate pinhole is a full-sun process. Shade and overcast run out the
clock. An oversized hole buys speed at the cost of softness, and on a 5x7
plate the extra blur is barely visible.

Ways to stretch the window:

- **Keep the camera humid.** A damp sponge or wet blotter inside the box,
  away from the light path. Historic trick for long wet plate exposures.
- **Shoot in cool weather** or early morning.
- **Larger hole**, as above. Two stops for going from 0.45 to 0.9 mm at
  100 mm depth.
- **Longer silver bath is not a fix.** Sensitivity does not keep rising.

## Camera

The relay box with a swappable back (see
[04-relay-camera-obscura.md](04-relay-camera-obscura.md)) is the starting
point. The plate back needs:

- **A plate holder that silver cannot corrode.** Silver nitrate eats brass
  and steel and stains wood. Standard 4x5 film holders work for glass plates
  with plastic corner shims; purpose-made wet plate holders use plastic or
  Delrin liners and a drip channel. Print the holder: PETG or ASA, one part,
  with a dark slide.
- **A shallower body.** 75 to 100 mm depth for 4x5. Either a separate short
  box with the same pinhole plate, or a removable spacer on the digital box
  so its depth can be cut in half.
- **Plate registration.** The collodion side faces the hole. A silver drip
  will run down the plate in the holder; a small sump at the bottom edge
  keeps it off the box.

### In-camera processing

The Dubroni (1864) did the whole wet plate process inside the camera: the
plate sat in a glass-lined chamber and the chemistry went in and out
through a port with a pipette. The pinhole version is a box with a sealed
plate chamber, a fill port, a drain, and a red window. No darkbox on
location. Worth a prototype once the basic process is working; it is the
kind of object that belongs in the show.

## Chemistry

Kit form (Bostick & Sullivan, Lund, UVP and others) or mix from scratch.
Cadmium-free "Old Workhorse" style collodion is the sensible default.

| Item | Role | Notes |
|---|---|---|
| Salted collodion | image layer | ether + alcohol; flammable, ventilate |
| Silver nitrate 9% bath | sensitizer | stains skin black, caustic to eyes; gloves, glasses |
| Iron sulfate developer | develops | ferrous sulfate, acetic acid, alcohol, water |
| Sodium thiosulfate 20% | fixer | not cyanide |
| Sandarac varnish | protects | lavender oil + alcohol; the plate is fragile until varnished |
| Glass or trophy aluminum | plate | glass edges sanded; aluminum for tintypes |
| Whiting + alcohol | plate cleaning | collodion will not adhere to a dirty plate |

Silver bath maintenance (sunning, filtering, pH) is the part that wears
people down. Keep the bath in a vertical tank with a lid and filter it
before each session.

## What the plate is

- **On clear glass, backed black:** ambrotype, a direct positive. One of a
  kind. Hang it.
- **On blackened aluminum:** tintype. Cheap, unbreakable, the same look.
- **On clear glass, not backed:** a collodion negative. Contact print it.
  Historically the negative for albumen prints; here the negative for
  cyanotype (see [06-diy-chemistry.md](06-diy-chemistry.md)). A pinhole
  collodion negative printed as a hand-coated cyanotype is entirely
  nineteenth-century and entirely home-made.

## Look

Pinhole plus collodion is soft on soft. The pinhole blur is a couple of
millimeters on a 5x7 plate; the collodion adds pour marks, edge chemistry,
and the blue-only tonality (white skies, black reds, luminous skin). The
combination has not been done much because wet plate people use lenses and
pinhole people use paper. That is a reason to do it.

## Day one plan

1. Buy or mix a small kit. Cut six 4x5 glass plates, sand the edges.
2. Build or adapt a 4x5 plate holder with plastic liners.
3. Use an existing film pinhole box at 75 to 100 mm depth, or a shallow
   spacer on the relay box.
4. Full sun, static subject, damp sponge in the box. Expose 5 minutes.
5. Develop in a changing bag or dark tent next to the camera. Fix in
   daylight. Rinse, dry, varnish over a spirit lamp.
6. Log plate, depth, hole, sun, temperature, exposure. Adjust hole size
   before adjusting anything else.

## Show

The process is a performance. Pour, silver, expose, develop, and the image
appears in the fixer in front of people. A pinhole box beside the digital
box, both fed by the same hole geometry, with the plates drying on a rack.

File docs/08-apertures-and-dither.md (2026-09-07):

# Odd apertures, and the dither catalogue

Asked: double slits, moire, anything to make it interesting; and the
receipt-printer dither looked like old PC graphics and the Game Boy Camera.
Mockups for all of it are in `mockups/out/look2_*.png`
(`experiments_sheet.png`) and `mockups/out/dither_*.png` (`dither_sheet.png`).

## The one rule that sorts the aperture ideas

A pinhole camera is a linear system. The image on the screen is the scene
convolved with the shape of the aperture. Every point in the scene becomes a
copy of the hole. That single fact predicts all of these:

- A **slit** makes every point a line: sharp across the slit, smeared along
  it. Anamorphic blur.
- **Two slits** make two smeared copies, shifted by the slit spacing. No
  fringes in daylight (see below for when there are).
- **Two crossed slits at different distances** give different focal lengths
  in x and y: a true anamorphic pinhole. Vertical slit at 200 mm and
  horizontal at 100 mm squeezes 2:1.
- **Several holes** make several overlapping copies, and add their light.
  Five holes, five times the light, five ghosts.
- A **shaped hole** (star, letter) stamps its shape on every point light. At
  night every streetlight is a star. In daylight the scene is just mush with
  starry highlights.
- A **hole array cannot make moire.** Convolution only weights the scene's
  existing frequencies; it never creates new ones. My first mockup of this
  was wrong and has been replaced.

## Where moire actually comes from

Moire is multiplication of two periodic patterns, and in this camera that
happens in three places, none of them the aperture:

1. **At the screen.** A screen printed with fine lines, or a mesh laid over
   it, multiplies the projected image. A picket fence projected onto a lined
   screen beats at the difference frequency. Walk toward the fence and the
   bands sweep as its projected period changes. Real, cheap, tunable.
2. **At the sensor.** The relay camera samples the screen on a pixel grid.
   Fine periodic detail near the pixel pitch aliases into bands. This is
   ordinary camera moire, and the fence on the screen will do it.
3. **At the printer.** A halftone dot screen or ordered dither is a periodic
   pattern multiplied into the image. Print a fence, get bands.

Mockup: `look2_06_moire`.

## Double slit: fringes need a small sensor

Fringe spacing is `lambda * L / d` (wavelength, slit-to-image distance,
slit separation). On the 200 mm box with slits 1 mm apart that is 0.13 mm,
a tenth of a screen-point, and white light smears it further. Invisible.

On the Pi HQ sensor with the lens off, the geometry flips in your favour.
Slits 0.12 mm apart, 5 mm from the sensor, under a red gel: fringe pitch is
about 16 microns, ten sensor pixels. Point the camera at streetlights at
night and every light becomes a vertical bar (from the slit length) carrying
horizontal fringes (from the slit pair). The "wrong" tiny-sensor camera is
the right one for interference. Mockup: `look2_03_double_slit_fringes`.

Slits at 0.05 mm width and 0.12 mm pitch are a laser-cut or photo-etched
part, not a knife job. A double-slit diffraction slide from a physics
supplier is a few dollars and drops into the C-mount cap.

## Zone plate

A Fresnel zone plate is a diffractive lens: concentric rings whose spacing
makes one wavelength focus at one distance. Compared with a pinhole of the
same focal length it is brighter (the open rings add up, roughly the number
of zones divided by 2 over a pinhole at the same resolution, call it two to
four stops) and its central spot can be smaller. The price is a big soft
halo from the other diffraction orders and strong colour: red focuses
nearer, blue farther, so the glow is chromatic. The look is a well-known
dreamy high-key glow with fringed edges. Mockup: `look2_08_zone_plate`.

Make one by laser-printing the ring pattern on transparency (fine for a
200 mm focal length, the outer rings are ~0.1 mm) or by ordering a
photo-etched plate. Design: ring radii `r_n = sqrt(n * f * lambda)`.

## Coded aperture: the computational pinhole

Replace the hole with a plate that is half open in a pseudo-random pattern
(a MURA, modified uniformly redundant array, prime size p). The screen shows
the scene shadowed through the pattern, an abstract mess. One correlation in
software with the matching decoding pattern recovers the picture.

Why bother: the plate passes about p^2 / 2 pinholes' worth of light. At
p = 101 that is roughly 5000 times a single pinhole, so the relay box's
half-hour interior exposure becomes a fraction of a second. Resolution is
p points across, set by the cell size, so at 101 it is Game Boy territory.
The raw capture and the decode are both images worth showing. This is
X-ray-astronomy technology; it works because our capture is digital.

Caveats that matter:

- Decoding assumes the scene is at infinity and fully inside the coded
  field. Nearer objects and the field edges decode with artefacts.
- The raw image has very low contrast, so it needs a clean, high-bit-depth
  capture. Noise in the raw becomes noise everywhere in the decode.
- The plate's cells must be small and sharp: 2 mm cells for p = 101 on a
  250 mm screen. Laser-cut steel or photo-etched brass.

Mockups: `look2_09_mura_mask`, `look2_10_mura_raw`, `look2_11_mura_decoded`.

## Two holes, two gels: an anaglyph straight out of the box

Two pinholes 65 mm apart, red gel on the left, cyan on the right. The two
images overlap on the screen with a parallax that depends on distance, and
the capture is already a red/cyan anaglyph. Put the glasses by the screen.
Nearer objects separate more, so a scene with something close works best.
Mockup: `look2_12_anaglyph` (fakes depth with a ground plane).

## Slit-scan onto the receipt roll

A vertical slit, and the relay camera reads one column per interval and the
printer prints it as one row. The roll is the film and the length is time.
A static scene prints as streaks; anything that crosses the slit prints as
itself, stretched by how slowly it crossed. A day is about a metre of paper.
Pure software on top of the relay box. Mockup: `look2_13_slit_scan`.

This is the scanner camera's aesthetic (see [03-scanner-camera.md](03-scanner-camera.md))
without the scanner, and with the printer doing the sweep.

## The dither catalogue

The receipt printer is a 1-bit device and every old 1-bit display had its
own dither. The pinhole image carries about 200 real points across, which
is exactly the resolution these styles were designed for. Sheet:
`mockups/out/dither_sheet.png`.

| Style | What it is | Read |
|---|---|---|
| Floyd-Steinberg | error diffusion, 1976 | smooth, "photographic", the printer default |
| Atkinson | Bill Atkinson's 1984 Mac dither, diffuses 6/8 of the error | lighter, crisper, blows highlights, drops shadow detail |
| Bayer 4x4 | ordered threshold matrix | the crosshatch of CGA/EGA-era art |
| Bayer 8x8 | larger matrix | smoother ramps, still a visible grid |
| Halftone dot, 45 degrees | newspaper screen | dots grow with darkness; moires against periodic subjects |
| Line screen | horizontal lines, thickness carries tone | engraving; suits the slit-scan strip |
| Game Boy Camera | 128 x 112, four greens, ordered dither | the look you remembered |
| CGA palette 1 | 320 x 200, black/cyan/magenta/white | cursed and lovely |
| 1-bit at 96 px | the pinhole's points quartered, then dithered | reads as the printer's own grain |

All of them are a few lines of numpy on the relay frame. Bayer and Atkinson
are the two that most say "old computer"; halftone and line screen most say
"print". A rotary switch on the box that picks the dither per print is a
cheap, legible piece of interaction.

## What survives as a build idea

- Screen printed with a line grid, swappable with the plain screen (moire).
- A double-slit slide in the Pi HQ cap, for night work.
- A laser-printed zone plate as a second aperture plate.
- A MURA plate, once the relay box works, for the fast/decoded mode.
- Two gelled holes for anaglyphs.
- Slit-scan mode and the dither switch in software.

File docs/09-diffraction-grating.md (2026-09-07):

# Can a diffraction grating be the lens?

Short answer: a plain grating cannot, because it bends light without
focusing it. A grating whose line spacing shrinks outward does focus, and
that is a zone plate. Both are useful here for different reasons. Mockups:
`mockups/out/look3_*.png`, sheet `grating_sheet.png`.

## Linear grating: a prism, not a lens

A grating with spacing `d` sends light of wavelength `lambda` off-axis by
`sin(theta) = m * lambda / d` for order `m`. Every wavelength goes a
different way, but nothing converges. Put one over the pinhole and the
pinhole still forms the image; the grating adds two rainbow copies of it.

Numbers on the 200 mm box with a 500 lines/mm film grating ($5):

| Wavelength | First-order angle | Displacement on the screen |
|---|---|---|
| 400 nm (violet) | 11.5° | 41 mm |
| 550 nm (green) | 16.0° | 57 mm |
| 700 nm (red) | 20.5° | 75 mm |

So each point of light becomes the point itself (zero order) plus a
34 mm rainbow on either side. At night with streetlights that is a
spectrograph: every light writes its spectrum, and sodium, LED and neon
sources look different. In daylight the whole scene gets two rainbow-smeared
ghosts overlaid, which is mostly mush. A crossed grating (the "rainbow
glasses" film, about 530 l/mm) gives four rainbows per light, on a cross.
Efficiency for a cheap sinusoidal film grating: roughly a third of the light
in zero order and a third in each first order.

Night piece, cheap, real, and it works in white light since dispersion
does not need coherence. Mockups: `look3_01_grating_night`, `look3_02_grating_day`.

## Zone plate: the grating that focuses

Rings at radii `r_n = sqrt(n * f * lambda)`. It is a circular grating whose
pitch falls with radius so every zone's first-order deflection lands at the
same focus. For the 200 mm box designed at 550 nm with 25 zones:

| Quantity | Value |
|---|---|
| Innermost zone radius | 0.33 mm |
| Outer diameter | 3.3 mm |
| Outermost zone width | 33 um |
| Focused spot (green) | ~0.07 mm, vs 1.2 mm for the pinhole |
| Light through the plate vs the optimum pinhole | ~12x (half of 25 zones open) |
| Of that, in the +1 focus | ~20 percent, so ~2.5x the pinhole, about 1.3 stops |
| Zero order | 25 percent of the total: a soft image through the whole 3.3 mm plate |
| Minus-one and higher orders | the rest, softer still |

So the zone plate image is a sharp green picture sitting on top of a pile
of soft copies of itself. That is the glow. Total light is many times a
pinhole's but most of it is fog, which is why real zone plate photographs
are low-contrast and dreamy.

Chromatic aberration is the other half of the character. Focal length is
inversely proportional to wavelength:

| Colour | Focal length | Defocus at the 200 mm screen | Blur diameter |
|---|---|---|---|
| Red 650 nm | 169 mm | 31 mm | 0.6 mm |
| Green 550 nm | 200 mm | 0 | sharp |
| Blue 450 nm | 244 mm | 44 mm | 0.6 mm |

Red and blue come out about as soft as the pinhole; green is roughly
fifteen times sharper. Mockups: `look3_03_zone_plate_pattern`,
`look3_04_zone_plate_capture`.

## Why the digital box makes the zone plate much better

Two things the film version cannot do:

- **The point spread function is known.** It is the sum of a sharp core
  and a few Gaussians of known size. Subtract the halo in software and the
  contrast comes back. Cheap deconvolution, no guessing.
- **Green carries the detail.** Take luminance from the sharp green channel
  and colour from the soft red and blue. The eye reads luminance for
  sharpness, so the result looks sharp in colour. Mockup:
  `look3_05_zone_plate_digital`.

A third option is mechanical: put the plate on a short rail and shoot red,
green and blue frames at their own foci (169, 200, 244 mm), then merge. Or
shoot under sodium light, which is monochromatic, and the plate is simply a
sharp fast lens.

Net: a printed transparency as the lens, deconvolved in software, gives a
picture several times sharper than the pinhole at a couple of stops faster.
Still a lensless, diffraction-only camera. Worth building.

## Related things that also count as "a grating as a lens"

- **Photon sieve.** The zone plate's rings replaced by many small holes
  distributed over each zone. Less halo, sharper, less light. Same file to
  make, different pattern.
- **Holographic optical element.** A hologram of a point source is a zone
  plate with a sinusoidal profile; volume holograms put most of the light in
  one order. Sold for AR displays; expensive for this.
- **Blazed or phase zone plate (kinoform).** Etched glass rather than
  printed black rings, 40 to nearly 100 percent in the focus. The
  diffractive elements in some camera lenses. Not home-makeable.
- **Fresnel lens.** Grooves, not lines; refractive, not diffractive. A page
  magnifier in the box is an ordinary lens camera obscura, bright and
  low-contrast. Different thing, often what people mean.

## Making a zone plate at this scale

Outer zone width is 33 um at 25 zones. Options:

| Method | Resolution | Fit |
|---|---|---|
| Laser printer on transparency | 20 um dots at 1200 dpi | marginal at 25 zones; fine at 10 |
| Print shop imagesetter film | ~7 um | good, ask for a film negative |
| Photograph a big printout onto litho film at 20:1 | ~10 um | the classic hobbyist route |
| Chrome-on-glass photomask | <1 um | best; ~$100+ |
| Buy (Lensbaby-style pinhole/zone plate optic, hobby kits) | made for 35 mm | wrong focal length for the box |

Fewer zones is easier to make and gives a smaller aperture with less fog;
more zones is sharper and brighter. Ten to twenty-five is the useful range.
Make it the same swappable plate as the pinhole, and keep the grating film
as a slip-over for night.

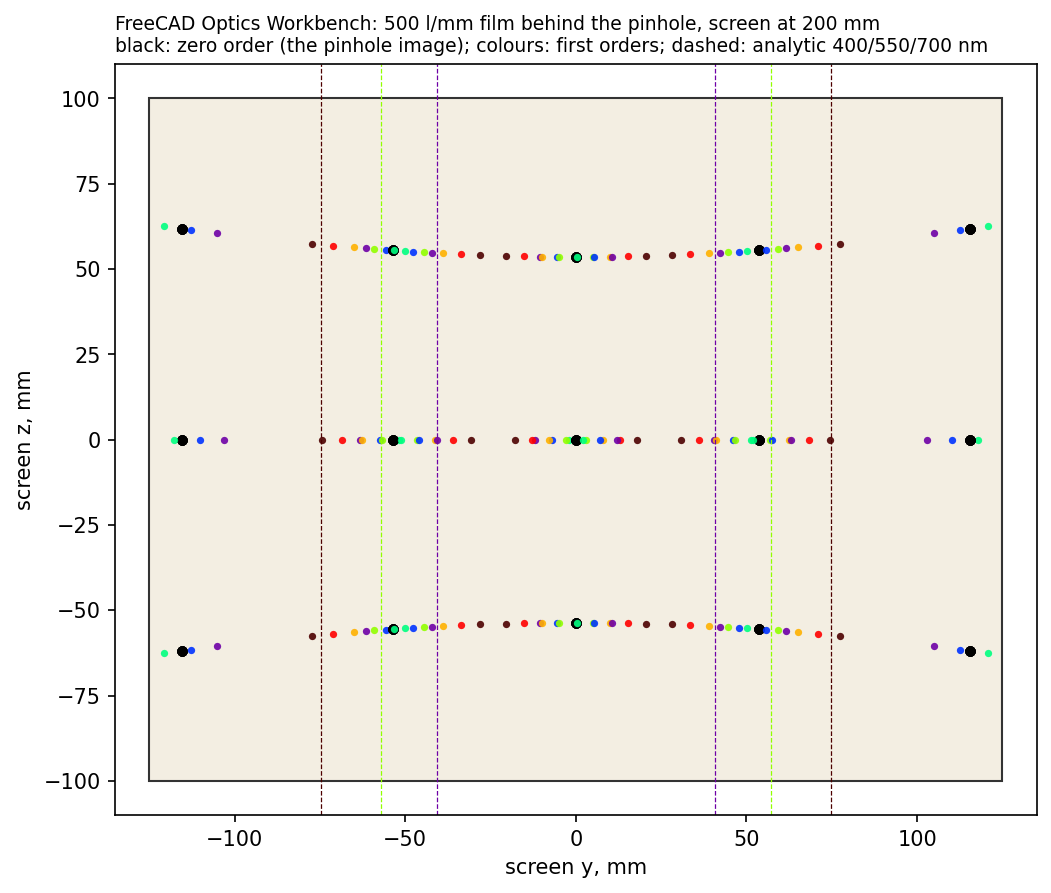
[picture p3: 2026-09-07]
mockups/out/optics_grating.png

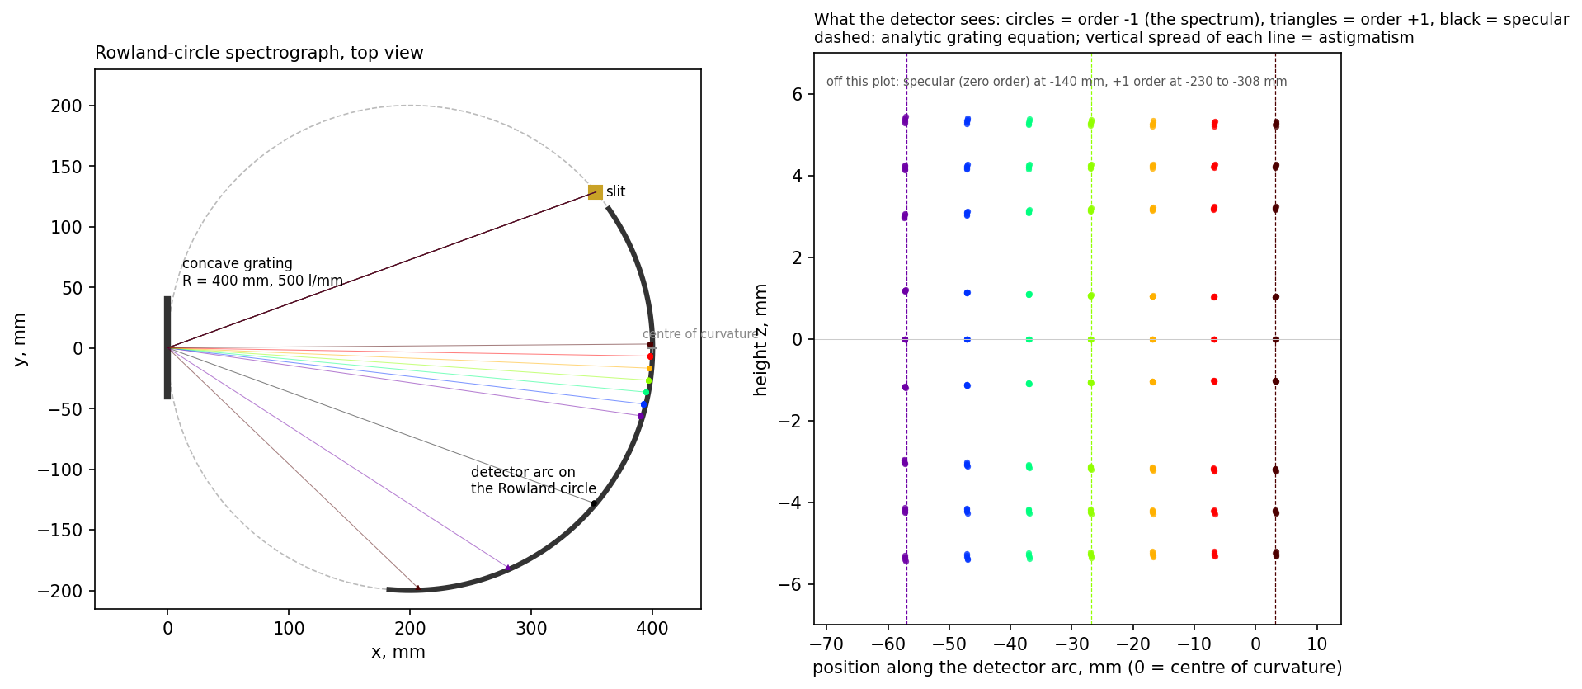
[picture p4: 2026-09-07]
mockups/out/optics_rowland.png

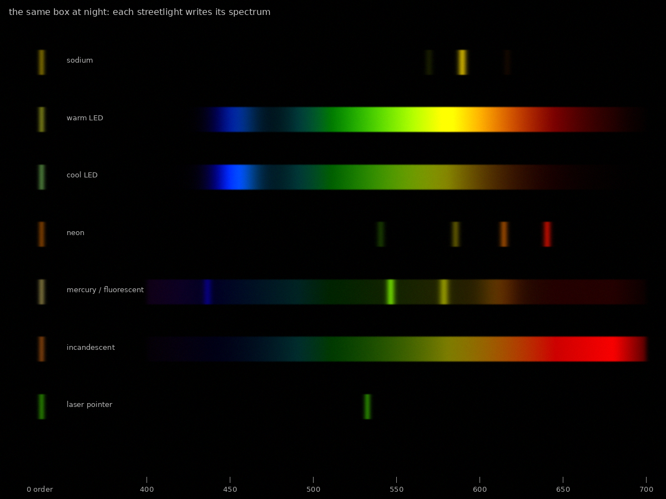
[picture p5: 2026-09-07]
mockups/out/look4_02_spectrograph_night.png

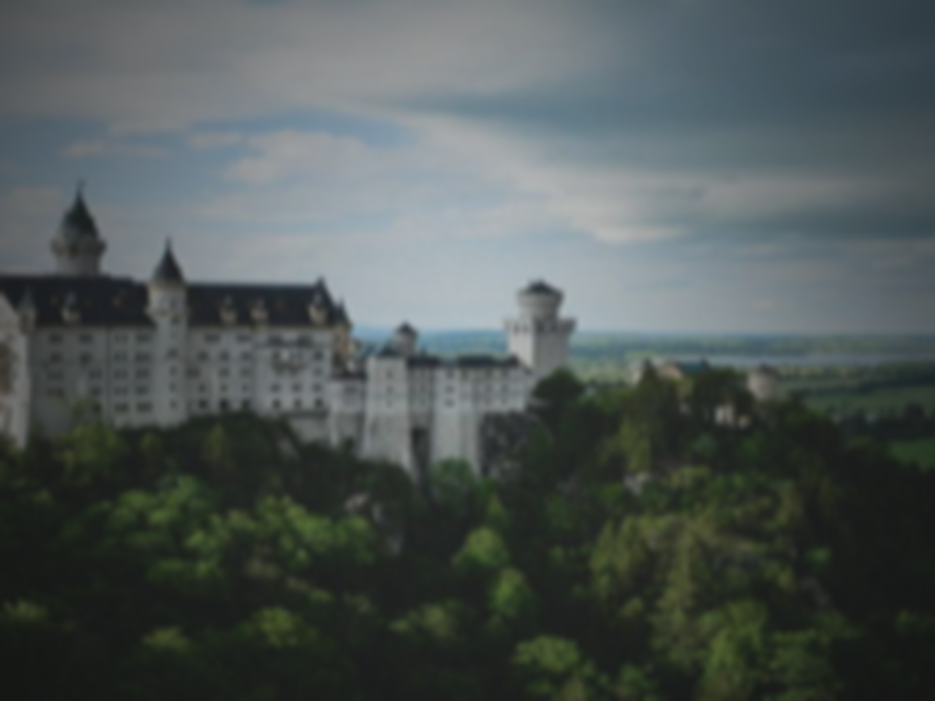
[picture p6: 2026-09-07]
mockups/out/look2_04_crossed_slits.png

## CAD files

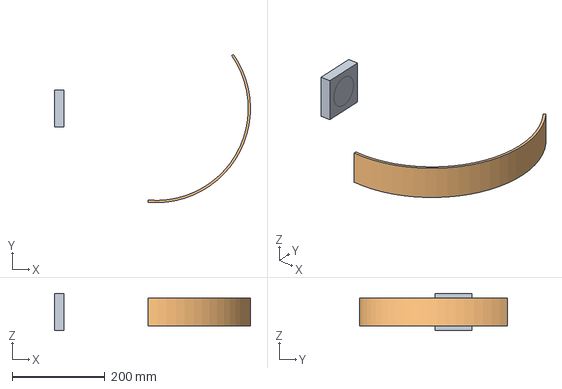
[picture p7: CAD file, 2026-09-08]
mockups/out/optics_rowland.FCStd
422.0 x 319.4 x 80.0 mm
ConcaveGrating
Detector

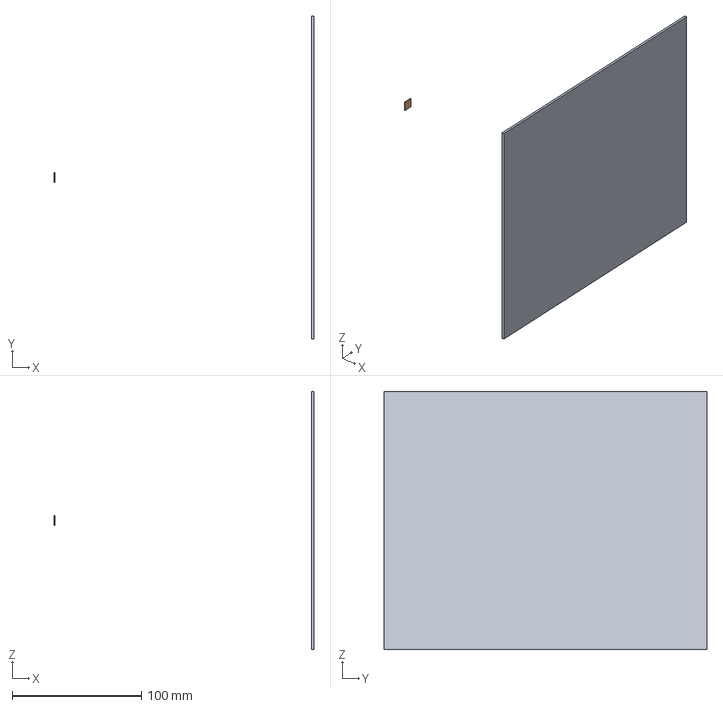
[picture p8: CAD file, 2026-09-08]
mockups/out/optics_grating.FCStd
201.0 x 250.0 x 200.0 mm
Screen
Film

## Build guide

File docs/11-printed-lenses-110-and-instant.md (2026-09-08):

# Printed cameras and lenses, 110 cartridges, instant film

Notes from a conversation about a half-remembered 3D printed camera, which
turned out to be Amos Dudley's SLO, and where it led: printed lenses, the
110 cartridge as a ready-made film transport, and instant film as both a
capture medium and a digital output. Ideas are summarised in
[IDEAS.md](../IDEAS.md); this is the detail.

## The SLO, and other printed cameras

The camera was the SLO (2016): a 35 mm camera printed entirely on a Form 2,
including its lens, iris and leaf shutter. The download in `~/Downloads`
is 34 STLs plus six PreForm `.form` files, no editable source. The lens was
printed in clear resin, then wet-sanded through the grits and polished.

Other printed cameras that ship as exported geometry only, for reference:

| Project | Format | Files |
|---|---|---|
| Amos Dudley, SLO | 35 mm, printed lens | STL + PreForm |
| Dora Goodman, Goodman One / Zone (GoodLAB) | 120, uses real lenses | STL + STP, free after sign-up |
| Velvia, Open 6x12 / 6x17 / 6x24 | 120 panoramic | STEP on Printables |
| OpenReflex (Léo Marius) | 35 mm SLR | STL |
| terraPin, P6*6 (schlem) | 120 pinhole | OpenSCAD source |

## Printed lenses

Dan has printed lenses since seeing the SLO, smoothing them by dipping in
clear resin and with spray lacquer. Notes on what governs the result:

- **Surface, not figure, is the usual limit.** Layer lines scatter light
  into haze. A dip coat fills them by surface tension and cures to a
  glass-like skin; it adds 0.1 to 0.3 mm of material and a meniscus at the
  edge. Lacquer is thinner but orange-peels and can craze resin.
- **Gravity makes a wedge.** A dipped lens left to cure hanging drains
  toward one edge. Rotating it slowly under the UV lamp while it cures
  keeps the coat even. Old trick from resin coating, cheap to rig with a
  small motor.
- **Droplet lens.** Skip printing the optical surface at all: a measured
  drop of clear UV resin on a printed ring forms a spherical cap by surface
  tension and cures in place. The print is the holder; the liquid makes the
  surface. Focal length follows drop volume, so it is repeatable, and there
  is nothing to sand. Same idea as the PDMS droplet microscope lenses.
- **A singlet is soft wide open.** Spherical aberration dominates at f/4;
  by f/8 a decent singlet resolves a few hundred points across a small
  frame. Chromatic aberration is fixed by the resin (Abbe number around
  40 to 50), and shows as colour fringes at edges.
- **Pinhole standards are generous.** A lens with a millimetre of blur on
  the relay screen is ten times sharper than the pinhole and hundreds of
  times brighter. On a 110 frame even a rough singlet beats the hole.

### The relay box as a lens test rig

Swap the pinhole plate for a printed lens plate and the box becomes a live
camera obscura: at f/4 to f/8 it is ten to twelve stops brighter than the
f/317 hole, so the Pi camera shows the screen in real time. Judge a lens in
seconds, compare two prints side by side, watch the focus as the plate
slides. This is the fastest feedback loop available for printed optics and
costs one extra plate. Pinhole mode stays slow; lens mode is live.

Lens plus Pi needs no shutter, because the sensor has one. Lens plus film
does: at f/8 and ISO 200 in sun the exposure is 1/800 s, which a sliding
cover cannot do. That is the reason the SLO needed a printed leaf shutter,
and the reason the 110 box below stays a pinhole.

## The 110 cartridge camera

The cartridge does everything a camera body usually does:

- **Film gate.** The frame window (13 x 17 mm) is in the cartridge; the
  film plane sits about a millimetre behind its face.
- **Transport.** Supply and take-up spools are inside; the camera turns the
  take-up hub with a thumbwheel or gear.
- **Pressure plate.** Moulded into the cartridge. Film flatness is famously
  poor in 110, which a pinhole does not care about.
- **Frame counter.** Printed on the backing paper, read through a small
  window in the camera back. One perforation per frame lets a pin stop the
  wind on better cameras; reading the numbers is enough here.

So the camera is a light-tight printed box with a hole in front of the
window, a thumbwheel, a sliding shutter and a peephole. No darkroom
loading; a bad print is a light leak rather than a jam. bergytone's 110
film pinhole camera on Thingiverse is an existing design (0.18 mm hole,
two-piece body, gear assembly) to start from or check against.

| Quantity | Value |
|---|---|
| Frame | 13 x 17 mm, 24 frames per cartridge |
| Hole about 25 mm from the film | 0.22 mm optimum, f/113 |
| Resolvable points across the frame | ~40 |
| Lomography Tiger 200 in full sun | ~1/4 s |
| Indoors | tens of seconds to minutes |

Soft, in the way the small-sensor Pi camera is soft, because the format is
small. That is the price of the convenience.

Film: Lomography makes 110 in black and white (Orca), colour (Tiger),
redscale (Lobster), slide (Peacock) and Metropolis. Developing: standard
reels do not take 16 mm film, but thinbegin's Pa-110 reel on Printables is
a free Paterson-fit design that holds a full cartridge, so the chain is
printed camera, caffenol, printed reel, all at home. The natural hand-out
camera for the show.

Design points if building one: make the pinhole plate the same swappable
part as the relay box's; keep the cartridge cavity a snug print with a
foam-backed door for light seal; the thumbwheel needs a ratchet or friction
so the film does not back-wind; put a red or opaque flip cover over the
counter window.

## Instant film

### Peel-apart pack film

Polaroid stopped in 2008 and Fujifilm's FP-100C in 2016; expired stock is
expensive and unreliable. The one current maker is Supersense in Vienna:
One Instant, hand-made Type 100 pack film in colour, black and white and
"Choco", sold in three-shot packs, plus a DIY kit since November 2023 where
the packs are assembled by hand for less per frame. A black and white
positive-negative version is a June 2026 limited edition with lead times of
about two months. Speed is around ISO 100.

| Quantity | Value |
|---|---|
| Pinhole at f/200 in full sun | ~1.6 s |
| Indoors | minutes, and instant chemistry loses reciprocity past a few seconds |

Mechanics: peel-apart needs two rollers that burst the pod and spread the
reagent as the tab is pulled. Roller gap and pressure are the one part not
worth printing. Either print a pinhole body that accepts a Polaroid 405
back, which carries its own rollers, or drill a hole in the lens board of a
Land camera.

Why it fits: the positive-negative stock gives a real 3.25 x 4.25 inch
negative. Contact print it and the cyanotype hangs beside the instant
positive, both from one press of the shutter, both hand-made. The wet
negative pressed onto watercolour paper is the classic image transfer, a
third print from the same shot.

### Home-made peel-apart: diffusion transfer

The chemistry behind pack film is diffusion transfer, and people make it
at home. Expose an ordinary paper negative, sandwich it face to face with a
receiver sheet with a developer paste between, wait five minutes in the
dark, peel: a positive on the receiver and a negative to fix. The Photrio
thread "Diffusion Transfer Printing recipes" is the working lab notebook,
covering receiver nucleation layers and thiosulphate/phenol pastes. It is
not instant in the camera, since the negative is shot separately and the
sandwich assembled in the dark, but it is a positive and a negative from
one paper exposure with kitchen-grade chemistry, and it belongs with the
caffenol and cyanotype work in [06](06-diy-chemistry.md). The Supersense
DIY kit is the packaged form of the same idea.

### Instax

Integral film, cheap and everywhere, ISO 800. The rollers live in the
camera, but Jollylook sells hand-crank Instax backs and printed pinhole
bodies exist. A pinhole at f/150 needs about 1/9 s in sun, and the print
appears in 90 seconds in front of whoever pressed the shutter. The
practical instant camera for the show.

### Instax as a digital output

The Instax Link printers (Mini, Square, Wide) take images over Bluetooth,
and the open-source InstaxBLE library drives them from a Pi in Python. The
Wide Link prints 800 x 1260 pixels, far beyond the pinhole's ~200 real
points. So the relay box can hand out an instant photograph beside the
receipt, with no chemistry on site. This joins the receipt printer and the
cyanotype negative as the third output of the digital box.

## Where this leaves the build list

- Relay box: add a lens plate (live mode) and an Instax Link (instant
  output) to the pinhole plate, receipt printer and cyanotype negative.
- 110 pinhole box: the hand-out camera; printed reel for home developing.
- Instax pinhole: the other hand-out camera, prints on the spot.
- Peel-apart: a 405-back pinhole body if One Instant POS/NEG is in stock;
  otherwise the diffusion-transfer experiment from paper negatives.
- Printed lenses: droplet lens and spin-cured dip, judged live on the
  relay box.

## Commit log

2026-09-07 Digital pinhole: notes, ideas, and mockups
    Notes toward a digital pinhole camera started during a pinhole photography
    show: three approaches, physics, the scanner-camera dead end, the relay
    camera obscura design, thermal paper and receipt output, DIY chemistry and
    cyanotype, wet plate pinhole, odd apertures and dither styles, gratings and
    zone plates. Mockups: simulated output looks, cross-section diagrams, a 3D
    section of the relay box, all regenerable from the scripts in mockups/.
    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
2026-09-07 Curved gratings: Rowland spectrograph box, rings, FreeCAD ray traces
    Concave grating spectrograph as the second head for the relay box (grating
    film on a makeup mirror, slit and detector strip on the Rowland circle),
    daylight and streetlight-fingerprint mockups, circular constant-pitch
    aperture (rainbow rings), and a cross-section diagram.
    FreeCAD Optics Workbench ray traces run headless under freecadcmd:
    linear grating behind the pinhole matches the grating equation to 0.5%;
    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
2026-09-07 Makefile: keep the optics JSON hit lists
    Mark intermediates secondary so make stops deleting the ray-trace JSON
    after plotting it.
    Claude-Session: https://claude.ai/code/session_01UKu35QyQEtJLszTQMUeKLh
2026-09-08 Ideas: 110 cartridge pinhole camera, printed lens
    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
2026-09-08 Save the FreeCAD ray-trace documents; printed-lens and DIY peel-apart ideas
    fc_optics.py now saves optics_*.FCStd next to the JSON so the traces open in
    FreeCAD's GUI (drop the rays' unserialisable last-hit reference first).
    Ignore FreeCAD's .FCBak backups.
    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
    [optics_grating.FCStd, optics_rowland.FCStd]
2026-09-08 docs/11: printed lenses, the 110 cartridge camera, instant film
    Write-up of the SLO thread: printed cameras and lenses (dip, spin-cure,
    droplet lens, the relay box as a live lens test rig), why lens plus film
    needs a real shutter, the 110 cartridge as a complete transport, peel-apart
    status and mechanics, home-made diffusion transfer, Instax pinhole, and the
    Instax Link as the digital box's third output.
    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
